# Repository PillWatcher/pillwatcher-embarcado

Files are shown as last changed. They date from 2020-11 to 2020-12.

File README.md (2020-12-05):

## Referência rápida:

### Estrutura:

- **esquematicos:** Arquivos desenvolvidos para geração dos esquemáticos e PCBs no Proteus;

- **microcontroladores:** Arquivos desenvolvidos para simulação do funcionamento dos microcontroladores no Proteus (Linguagem C);

- **software_embarcado:** Arquivos desenvolvidos para funcionamento do sistema embarcado (Linguagem Python 3).

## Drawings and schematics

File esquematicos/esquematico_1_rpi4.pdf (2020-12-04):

## RPI4

## DSI/CSI

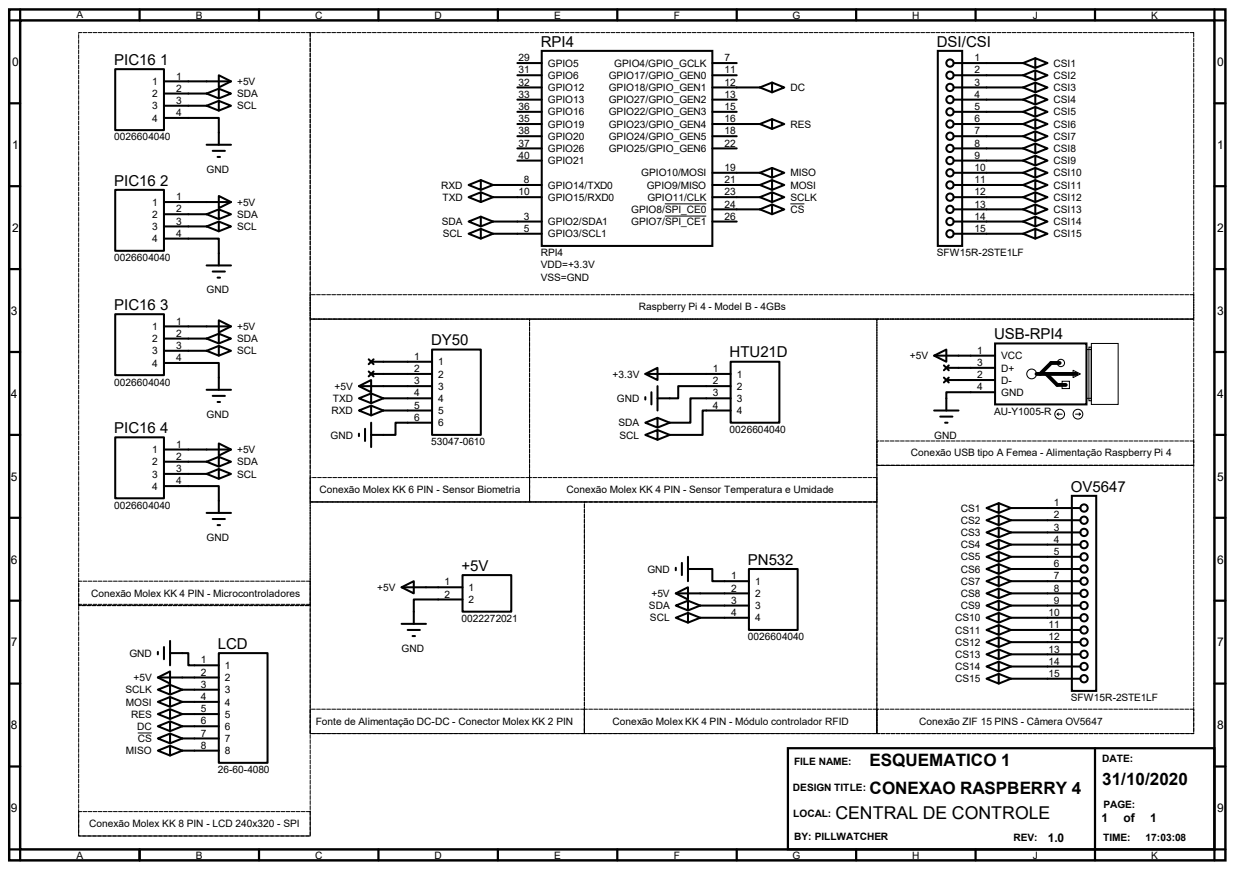
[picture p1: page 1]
DATE:; PAGE:; PILLWATCHER; 9 LOCAL:; REV: 1.0; TIME:; GPIO2/SDA1 3 GPIO3/SCL1 5; GPIO4/GPIO_GCLK; GPIO17/GPIO_GEN0; GPIO27/GPIO_GEN2; GPIO22/GPIO_GEN3; GPIO10/MOSI; GPIO9/MISO; GPIO11/CLK; GPIO5 29 GPIO6 31; GPIO13 33; GPIO19 35; GPIO26 37; GPIO15/RXD0 10; GPIO18/GPIO_GEN1; GPIO23/GPIO_GEN4; GPIO24/GPIO_GEN5; GPIO25/GPIO_GEN6; GPIO8/SPI_CE0; GPIO7/SPI_CE1; GPIO12 32; GPIO16 36; GPIO20 38; GPIO21 40; GPIO14/TXD0 8; RPI4 VDD=+3.3V VSS=GND; SFW15R-2STE1LF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

Raspberry Pi 4 - Model B - 4GBs

GND
Conexão USB tipo A Femea - Alimentação Raspberry Pi 4

Conexão Molex KK 6 PIN - Sensor Biometria

Conexão Molex KK 4 PIN - Sensor Temperatura e Umidade

Conexão Molex KK 4 PIN - Microcontroladores

Fonte de Alimentação DC-DC - Conector Molex KK 2 PIN

Conexão Molex KK 4 PIN - Módulo controlador RFID

Conexão ZIF 15 PINS - Câmera OV5647
ESQUEMATICO 1

FILE NAME:
DESIGN TITLE: CONEXAO RASPBERRY 4
CENTRAL DE CONTROLE

Conexão Molex KK 8 PIN - LCD 240x320 - SPI

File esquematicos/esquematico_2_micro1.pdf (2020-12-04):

## PIC16

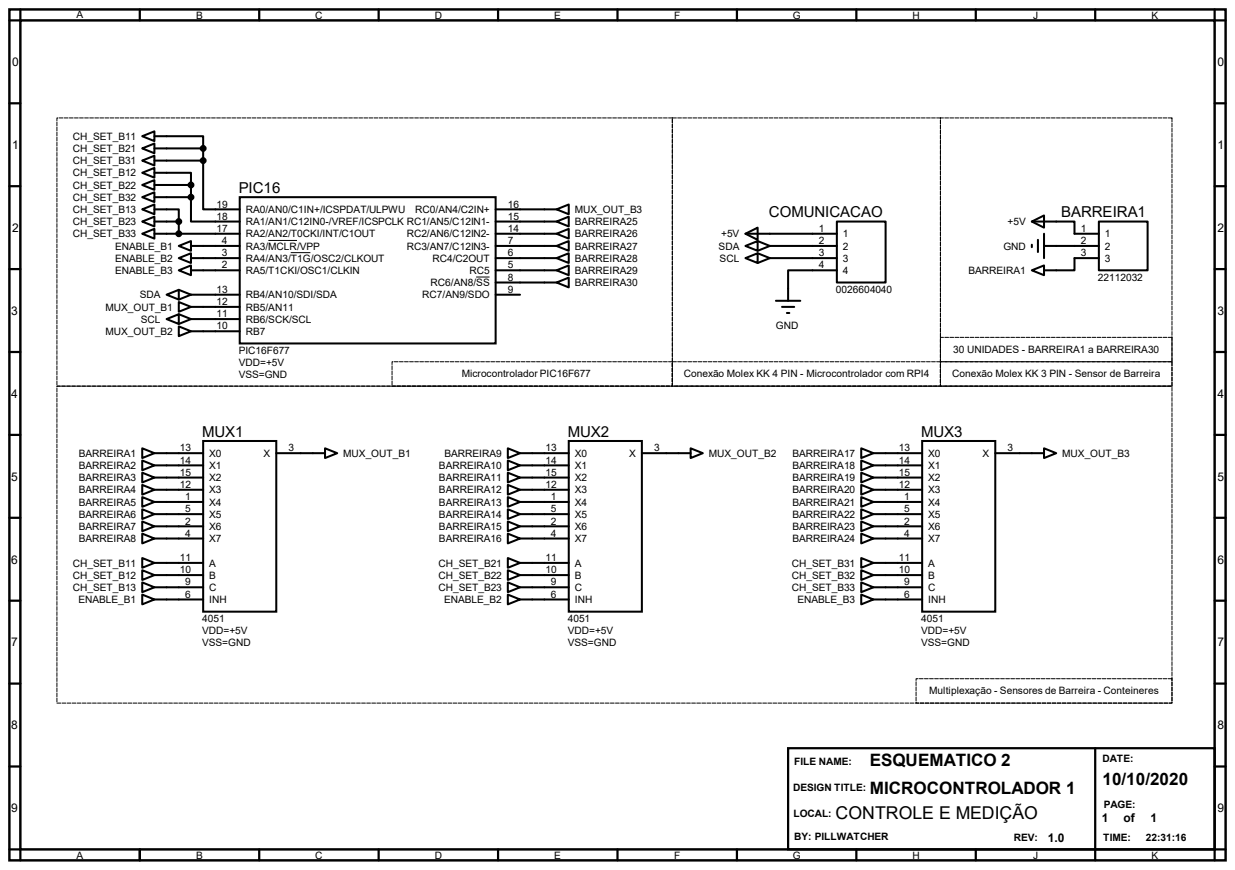
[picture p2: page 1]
DATE:; PAGE:; ESQUEMATICO 2; PILLWATCHER; 9 LOCAL:; REV: 1.0; TIME:; RA0/AN0/C1IN+/ICSPDAT/ULPWU 19; RC4/C2OUT; RA4/AN3/T1G/OSC2/CLKOUT 3 RA5/T1CKI/OSC1/CLKIN 2; RB4/AN10/SDI/SDA 13 RB5/AN11 12 RB6/SCK/SCL 11; RA1/AN1/C12IN0-/VREF/ICSPCLK 18; RA3/MCLR/VPP 4; RA2/AN2/T0CKI/INT/C1OUT 17; RC7/AN9/SDO; PIC16F677 VDD=+5V; VSS=GND; Microcontrolador PIC16F677; 9 INH 6; MUX1; 4051 VDD=+5V VSS=GND; BARREIRA1 BARREIRA2 BARREIRA3 BARREIRA4; BARREIRA6; BARREIRA5; BARREIRA7 BARREIRA8; MUX2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

Conexão Molex KK 4 PIN - Microcontrolador com RPI4

Conexão Molex KK 3 PIN - Sensor de Barreira

Multiplexação - Sensores de Barreira - Conteineres

FILE NAME:
DESIGN TITLE: MICROCONTROLADOR 1
CONTROLE E MEDIÇÃO

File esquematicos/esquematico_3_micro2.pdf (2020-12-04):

## PIC16

R1

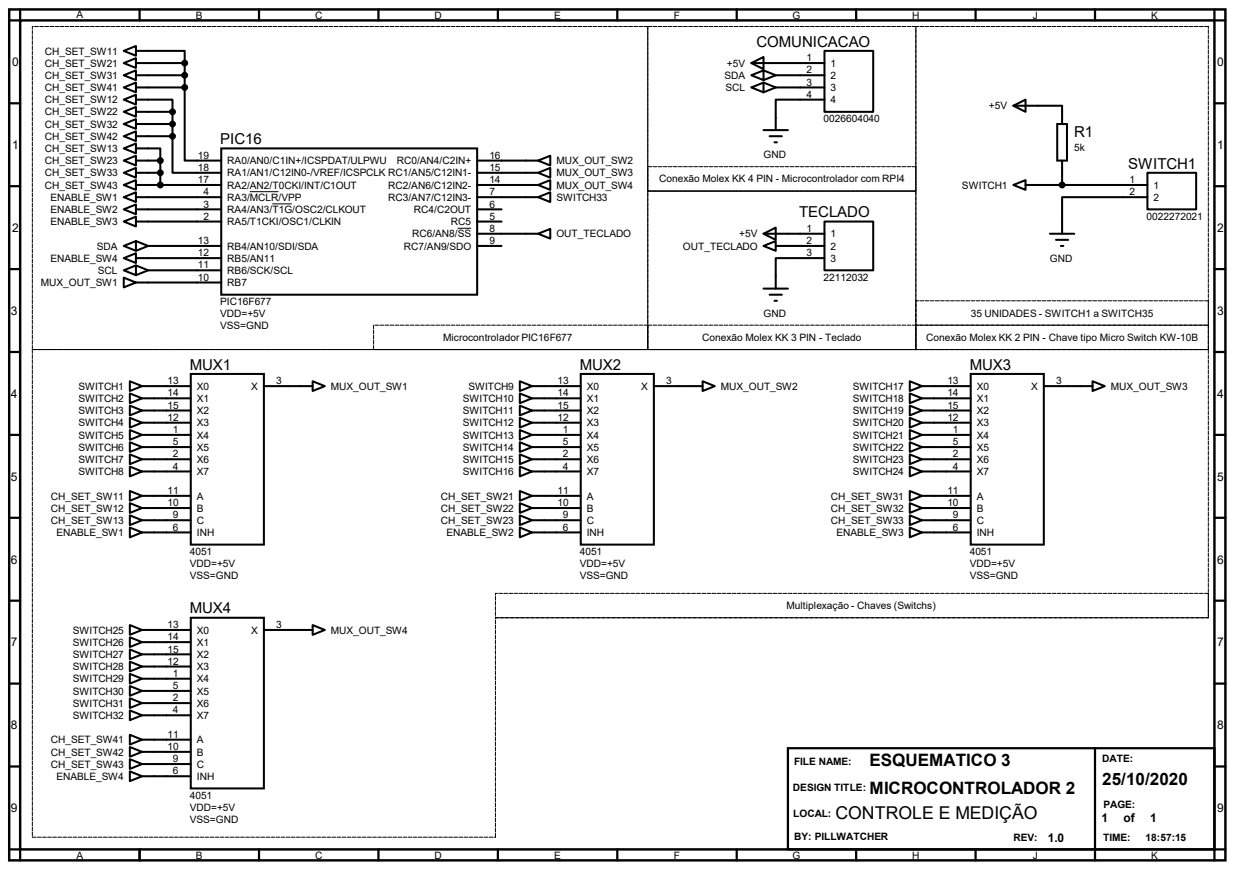
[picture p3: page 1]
DATE:; PAGE:; ESQUEMATICO 3; PILLWATCHER; 9 LOCAL:; REV: 1.0; TIME:; RA0/AN0/C1IN+/ICSPDAT/ULPWU 19; RC4/C2OUT; RA4/AN3/T1G/OSC2/CLKOUT 3 RA5/T1CKI/OSC1/CLKIN 2; RB4/AN10/SDI/SDA 13 RB5/AN11 12 RB6/SCK/SCL 11; RA1/AN1/C12IN0-/VREF/ICSPCLK 18; RA3/MCLR/VPP 4; RA2/AN2/T0CKI/INT/C1OUT 17; RC7/AN9/SDO; PIC16F677 VDD=+5V VSS=GND; Microcontrolador PIC16F677; 9 INH 6; MUX1; 4051 VDD=+5V VSS=GND; SWITCH1 SWITCH2 SWITCH3 SWITCH4; SWITCH6; SWITCH5; SWITCH7 SWITCH8; MUX2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

Conexão Molex KK 4 PIN - Microcontrolador com RPI4

Conexão Molex KK 3 PIN - Teclado

Multiplexação - Chaves (Switchs)

FILE NAME:
DESIGN TITLE: MICROCONTROLADOR 2
CONTROLE E MEDIÇÃO

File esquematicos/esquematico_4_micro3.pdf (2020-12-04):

## PIC16 SOLENOIDE

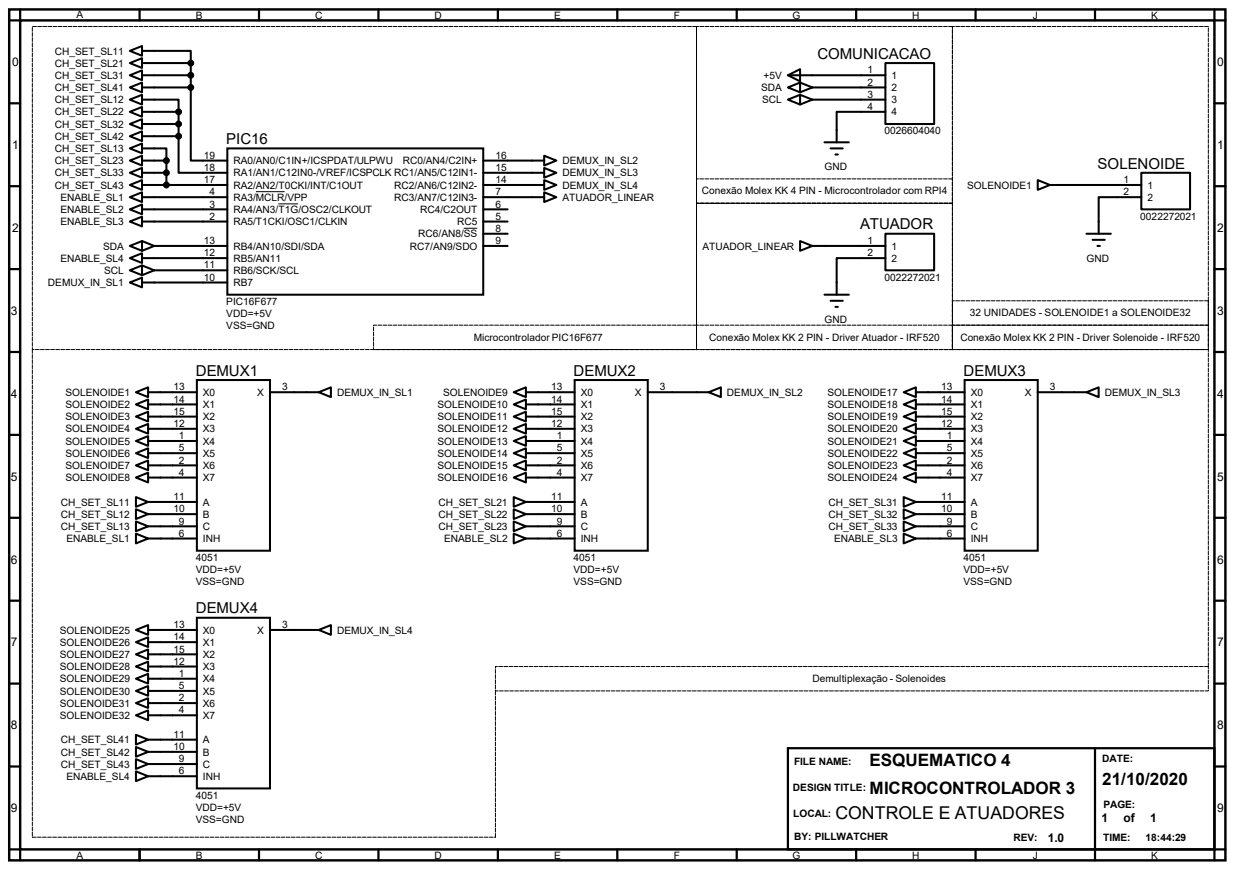
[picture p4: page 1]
DATE:; PAGE:; ESQUEMATICO 4; PILLWATCHER; 9 LOCAL:; REV: 1.0; TIME:; RA0/AN0/C1IN+/ICSPDAT/ULPWU 19; RC4/C2OUT; RA4/AN3/T1G/OSC2/CLKOUT 3 RA5/T1CKI/OSC1/CLKIN 2; RB4/AN10/SDI/SDA 13 RB5/AN11 12 RB6/SCK/SCL 11; RA1/AN1/C12IN0-/VREF/ICSPCLK 18; RA3/MCLR/VPP 4; RA2/AN2/T0CKI/INT/C1OUT 17; RC7/AN9/SDO; PIC16F677 VDD=+5V VSS=GND; Microcontrolador PIC16F677; 9 INH 6; DEMUX1; 4051 VDD=+5V VSS=GND; DEMUX2; DEMUX3; Demultiplexação - Solenoides; Conexão Molex KK 2 PIN - Driver Solenoide - IRF520; GND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

Conexão Molex KK 4 PIN - Microcontrolador com RPI4

Conexão Molex KK 2 PIN - Driver Atuador - IRF520

FILE NAME:
DESIGN TITLE: MICROCONTROLADOR 3
CONTROLE E ATUADORES

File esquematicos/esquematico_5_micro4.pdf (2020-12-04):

## PIC16 MOTOR DC

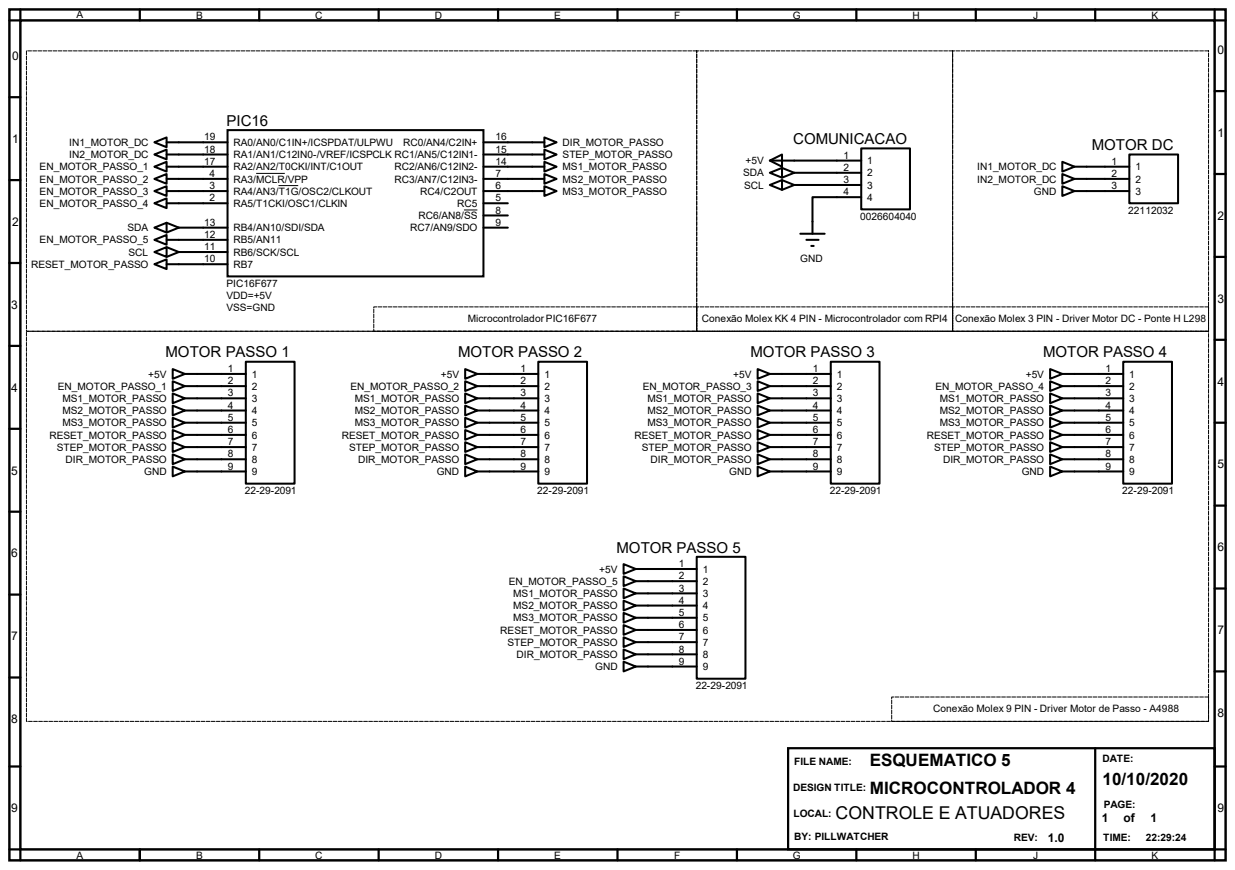
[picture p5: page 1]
DATE:; PAGE:; ESQUEMATICO 5; PILLWATCHER; 9 LOCAL:; REV: 1.0; TIME:; RA0/AN0/C1IN+/ICSPDAT/ULPWU 19; RC4/C2OUT; RA4/AN3/T1G/OSC2/CLKOUT 3 RA5/T1CKI/OSC1/CLKIN 2; RB4/AN10/SDI/SDA 13 RB5/AN11 12 RB6/SCK/SCL 11; RA1/AN1/C12IN0-/VREF/ICSPCLK 18; RA3/MCLR/VPP 4; RA2/AN2/T0CKI/INT/C1OUT 17; RC7/AN9/SDO; PIC16F677 VDD=+5V VSS=GND; Microcontrolador PIC16F677; IN1_MOTOR_DC IN2_MOTOR_DC EN_MOTOR_PASSO_1 EN_MOTOR_PASSO_2 EN_MOTOR_PASSO_3 EN_MOTOR_PASSO_4; EN_MOTOR_PASSO_5; RESET_MOTOR_PASSO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

Conexão Molex KK 4 PIN - Microcontrolador com RPI4
MOTOR PASSO 3

Conexão Molex 3 PIN - Driver Motor DC - Ponte H L298

Conexão Molex 9 PIN - Driver Motor de Passo - A4988

FILE NAME:
DESIGN TITLE: MICROCONTROLADOR 4
CONTROLE E ATUADORES

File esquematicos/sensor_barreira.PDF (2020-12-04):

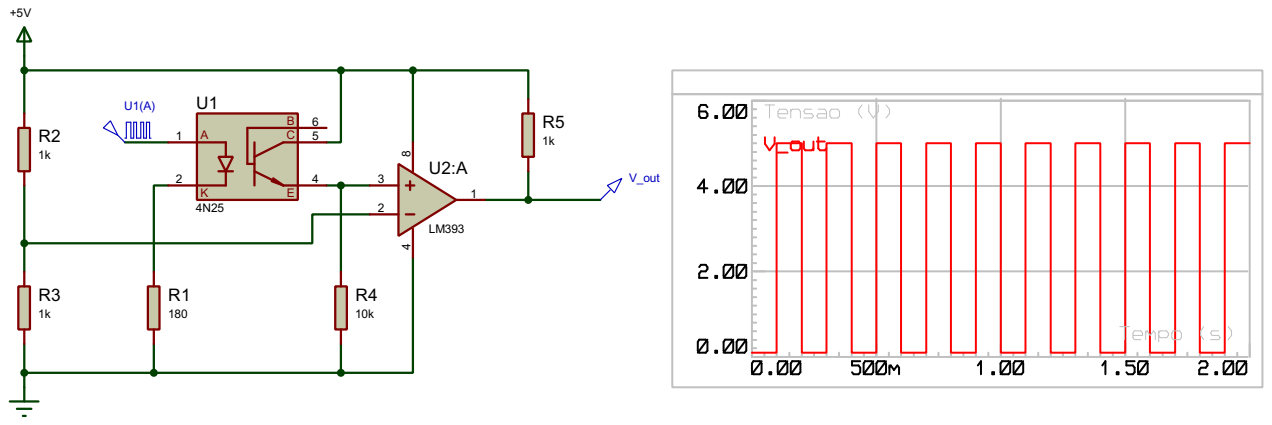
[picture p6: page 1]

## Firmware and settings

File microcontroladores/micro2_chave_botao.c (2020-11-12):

#include <16F677.h>

#device ADC=10
//Configuracao FUSES
#FUSES NOWDT
#FUSES NOHS
#FUSES INTRC_IO
#FUSES NOPROTECT
#FUSES NOBROWNOUT
#FUSES NOMCLR
#FUSES NOCPD
#FUSES NOPUT




#use delay(clock=8MHz)

#use i2c(SLAVE, SDA=PIN_B4, SCL=PIN_B6, address=0xA0, FORCE_HW)

#use standard_io (B)


#define PINO_A PIN_A0
#define PINO_B PIN_A1
#define PINO_C PIN_A2
#define PINO_EN1 PIN_A3
#define PINO_EN2 PIN_A4
#define PINO_EN3 PIN_A5
#define PINO_EN4 PIN_B5

int read_sensor();

// {C,B,A,E1,E2,E3,E4,PINOUT}
const BYTE sensores[34][8]={
   {0,0,0 ,1,1,1,1,PIN_C6},
   {0,0,0 ,0,1,1,1,PIN_B7},
   {0,0,1 ,0,1,1,1,PIN_B7},
   {0,1,0 ,0,1,1,1,PIN_B7},
   {0,1,1 ,0,1,1,1,PIN_B7},
   {1,0,0 ,0,1,1,1,PIN_B7},
   {1,0,1 ,0,1,1,1,PIN_B7},
   {1,1,0 ,0,1,1,1,PIN_B7},
   {1,1,1 ,0,1,1,1,PIN_B7},
   {0,0,0 ,1,0,1,1,PIN_C0},
   {0,0,1 ,1,0,1,1,PIN_C0},
   {0,1,0 ,1,0,1,1,PIN_C0},
   {0,1,1 ,1,0,1,1,PIN_C0},
   {1,0,0 ,1,0,1,1,PIN_C0},
   {1,0,1 ,1,0,1,1,PIN_C0},
   {1,1,0 ,1,0,1,1,PIN_C0},
   {1,1,1 ,1,0,1,1,PIN_C0},
   {0,0,0 ,1,1,0,1,PIN_C1},
   {0,0,1 ,1,1,0,1,PIN_C1},
   {0,1,0 ,1,1,0,1,PIN_C1},
   {0,1,1 ,1,1,0,1,PIN_C1},
   {1,0,0 ,1,1,0,1,PIN_C1},
   {1,0,1 ,1,1,0,1,PIN_C1},
   {1,1,0 ,1,1,0,1,PIN_C1},
   {1,1,1 ,1,1,0,1,PIN_C1},
   {0,0,0 ,1,1,1,0,PIN_C2},
   {0,0,1 ,1,1,1,0,PIN_C2},
   {0,1,0 ,1,1,1,0,PIN_C2},
   {0,1,1 ,1,1,1,0,PIN_C2},
   {1,0,0 ,1,1,1,0,PIN_C2},
   {1,0,1 ,1,1,1,0,PIN_C2},
   {1,1,0 ,1,1,1,0,PIN_C2},
   {1,1,1 ,1,1,1,0,PIN_C2},
   {0,0,0 ,1,1,1,1,PIN_C3} 
};
BYTE incoming, state; // I2C vars
BYTE response,sensor;
#INT_SSP
void ssp_interupt ()
{
   state = i2c_isr_state();
   
   if(state == 1){
      incoming = i2c_read();
      sensor = incoming;
   }else if(state >= 0x80){
      response=read_sensor();  
      delay_ms(10);
      i2c_write(response);
   }else     
      i2c_read();
}


int main (void)
 { 
   set_tris_a(0);
   set_tris_b(0b11011111);
   set_tris_c(0xFF);

   enable_interrupts(INT_SSP);
   enable_interrupts(GLOBAL);
   setup_vref(FALSE);
   setup_oscillator(OSC_8MHZ);
   setup_comparator(NC_NC_NC_NC);
   setup_adc(ADC_CLOCK_DIV_8);
   setup_adc_ports(sAN8,VSS_VDD);

    
   set_adc_channel(8); 
   delay_us(10);
   
   output_high(PIN_A3);
   output_high(PIN_A4);
   output_high(PIN_A5);
   output_high(PIN_B5);
   while (1)
      ;
   return 0;
 }   

int read_sensor(){
   int leitura;
   long leituraAdc;
   if(sensor==0){
      leituraAdc = read_adc();
      if(leituraAdc < 125)
	 leitura = 1;
      else if(leituraAdc >= 125 && leituraAdc < 300)
	 leitura = 2;
      else if(leituraAdc >= 300 && leituraAdc < 500)
	 leitura = 3;
      else if(leituraAdc >= 500 && leituraAdc < 700)
	 leitura = 4;
      else if(leituraAdc >= 700)
	 leitura = 5;    
      } else
      {
	 output_bit(PINO_C, sensores[sensor][0]);
	 output_bit(PINO_B, sensores[sensor][1]);
	 output_bit(PINO_A, sensores[sensor][2]);
	 output_bit(PIN_A3, sensores[sensor][3]);
	 output_bit(PIN_A4, sensores[sensor][4]);
	 output_bit(PIN_A5, sensores[sensor][5]);
	 output_bit(PIN_B5, sensores[sensor][6]);
	 delay_ms(10);
	 leitura = input(sensores[sensor][7]);
	 delay_ms(10); 
      }
   return leitura;
}

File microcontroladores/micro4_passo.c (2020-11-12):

#include <16F677.h>

//Configuracao FUSES
#FUSES NOWDT
#FUSES NOHS
#FUSES INTRC_IO
#FUSES NOPROTECT
#FUSES NOBROWNOUT
#FUSES NOMCLR
#FUSES NOCPD
#FUSES NOPUT

#use delay(clock=8MHz)

#use i2c(SLAVE, SDA=PIN_B4, SCL=PIN_B6, address=0xA0, FORCE_HW)


#define IN1 PIN_A0
#define IN2 PIN_A1
#define MS1 PIN_C2
#define MS2 PIN_C3
#define MS3 PIN_C4
#define EN1 PIN_A2
#define EN2 PIN_A3
#define EN3 PIN_A4
#define EN4 PIN_A5
#define EN5 PIN_B5
#define DIR PIN_C0
#define STEP PIN_C1
#define RST PIN_B7

int write_atuador();

// {E1,E2,E3,E4,E5}
const BYTE atuadores[6][5]={
{1,1,1,1,1},
{0,1,1,1,1},
{1,0,1,1,1},
{1,1,0,1,1},
{1,1,1,0,1},
{1,1,1,1,0},
};
BYTE incoming, state; 
BYTE response, atuador,direcao,passos,periodo;
#INT_SSP
void ssp_interupt ()
{
   state = i2c_isr_state();
   
   if(state == 1){
      incoming = i2c_read();
      atuador = incoming;
   }else if(state == 2){
      incoming = i2c_read();
      direcao = incoming; 
   }else if(state == 3){
      incoming = i2c_read();
      passos = incoming;  //passos do motor ou aticação motor dc
   }else if(state == 4){
      incoming = i2c_read();
      periodo = incoming; 
      write_atuador();
   }else if(state >= 0x80){
      response=atuador;
      i2c_write(response);
   }else     
      i2c_read();
}


int main (void)
 { 
   enable_interrupts(INT_SSP);
   enable_interrupts(GLOBAL);
    set_tris_a(0);
    setup_vref(FALSE);
    output_high(PIN_A3);
    output_high(PIN_A4);
    output_high(PIN_A5);
    output_high(PIN_B5);
   while (1)
      ;
   return 0;
 }   

void write_atuador(){
   output_bit(EN1, atuadores[atuador][0]);
   output_bit(EN2, atuadores[atuador][1]);
   output_bit(EN3, atuadores[atuador][2]);
   output_bit(EN4, atuadores[atuador][3]);
   output_bit(EN5, atuadores[atuador][4]);
   if(atuador > 0){
      for(int i=1;i<=passos;i++){
	 output_high(STEP);
	 delay_ms(periodo);
	 output_low(STEP);
	 delay_ms(periodo);
	 }
   }else if(direcao == 1){
      output_bit(IN1,passos);
      output_bit(IN2,FALSE);
   }else{
      output_bit(IN1,FALSE);
      output_bit(IN2,passos);
      }
   return ;
}

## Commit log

2020-11-12 Atualização de microcontroladores
2020-12-04 Reorganização do repositório e adição dos arquivos faltantes
    [sensor_barreira - CADCAM Bottom Assembly.GBR, sensor_barreira - CADCAM Bottom Copper.GBR, sensor_barreira - CADCAM Bottom SMT Paste.GBR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]
